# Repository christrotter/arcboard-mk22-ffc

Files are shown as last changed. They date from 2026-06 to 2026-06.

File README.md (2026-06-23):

# arcboard-mk22-ffc
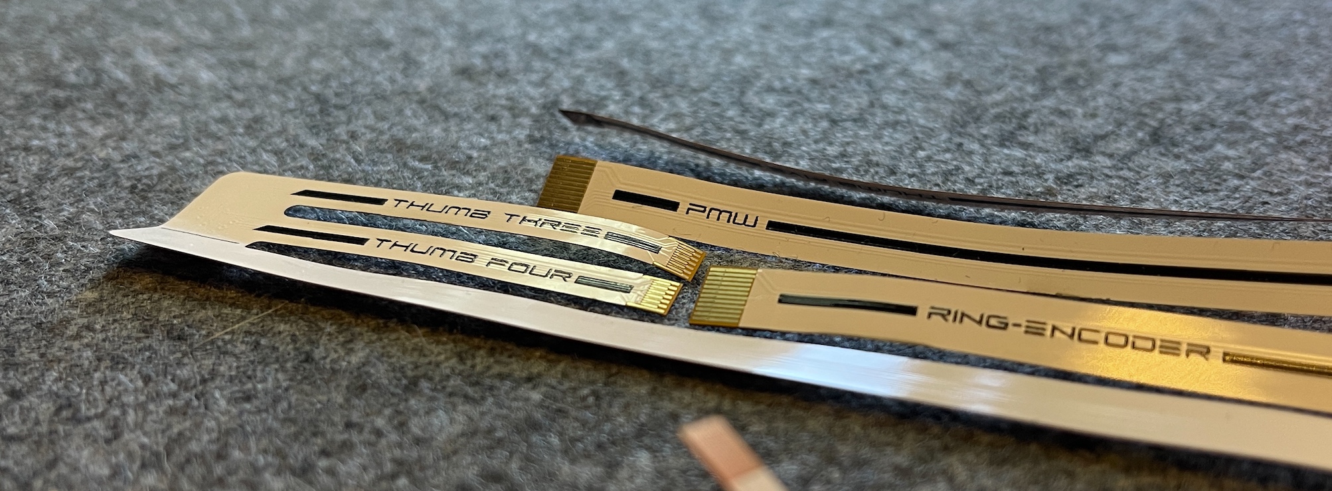
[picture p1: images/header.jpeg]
Header

FFC wiring harness for the Arcboard mk22's [mainboard](https://github.com/christrotter/arcboard-stm32-mk2).  Hooks up a whole pile of keys, peripherals, and indicators with a single cable.  

The goal was to reduce manual soldering as much as possible while also reducing the number of FFC's coming off the mainboard.  [The old mainboard](https://github.com/christrotter/arcboard-stm32) had 10 FFCs coming off at all angles and it was a nightmare to install.

All questions, and more, answered here: 
[Walking through the process of making a custom FFC.](https://docs.google.com/document/d/1AaeZN3C4SzMbZbiK-B96kASK0Lhcgzr27FD6T2ESAdA/edit?usp=sharing)

And if you're interested in learning more about the board itself:
[The mk22 build journal - in great detail.](https://docs.google.com/document/d/1yYdNSWEpefUsuglO4ZzcITcItB_Wx3liXkT57BLO2Ac/edit?usp=sharing)

# ordering
See the 'making a custom FFC' doc for great detail on this.

The different pitch sizes require different total FFC thicknesses.
- 0.3mm-pitch -> 0.2mm thick FFC, including stiffener
- 0.5mm-pitch -> 0.3mm thick FFC, including stiffener (connector specs range from `0.27-0.33mm` to `0.29-0.31mm`)

## peripherals
But what peripherals does this hook up?
- six [Cyboard column PCBs](https://cyboard.digital/products/dactyl-flex-pcbs)
- five [Cyboard thumb key PCBs](https://cyboard.digital/products/dactyl-flex-pcbs)
- [main LED indicator PCB](https://github.com/christrotter/para-led-ogram)
- [ring gear encoder indicator PCB](https://github.com/christrotter/ring-led-pcb)
- [an ST7789v2 LCD adapter PCB](https://github.com/christrotter/lcd-adapter-pcb)
- [two led-backlit EC10 encoders](https://github.com/christrotter/top-encoder-pcb)
- [one non-lit EC10 encoder](https://github.com/christrotter/mouse-encoder-pcb)
- [STM32 mainboard](https://github.com/christrotter/arcboard-stm32)
- [a dpad (5-way)](https://github.com/christrotter/led-pad)
- [three paddles (3x 5-way)](https://github.com/christrotter/multi-paddle-pcb)
- [PMW3360 to FFC](https://github.com/christrotter/charybdis-pmw-3360-sensor-pcb/tree/arcboarding) (*forked from* [Charybdis](https://github.com/Bastardkb/charybdis-pmw-3360-sensor-pcb))

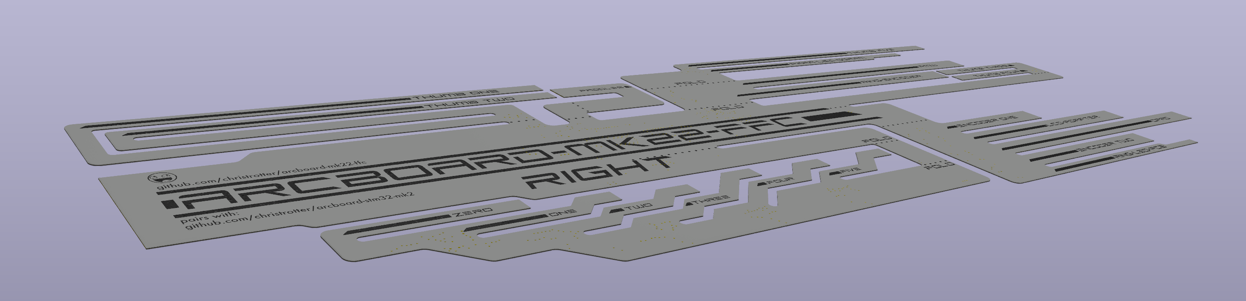
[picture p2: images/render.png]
Render

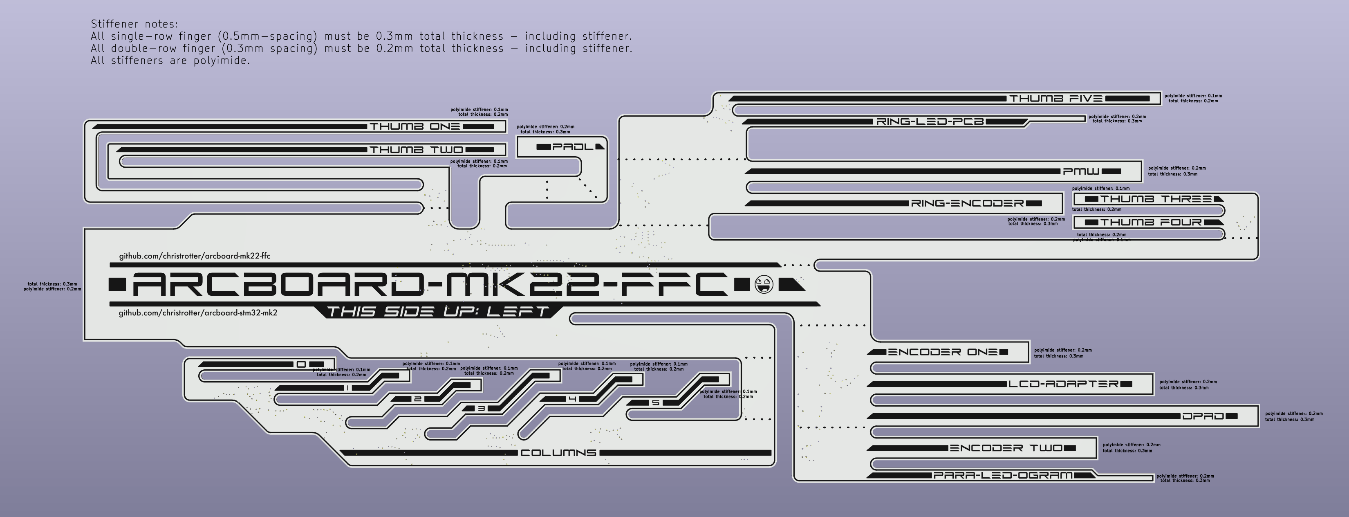
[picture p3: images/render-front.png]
Front

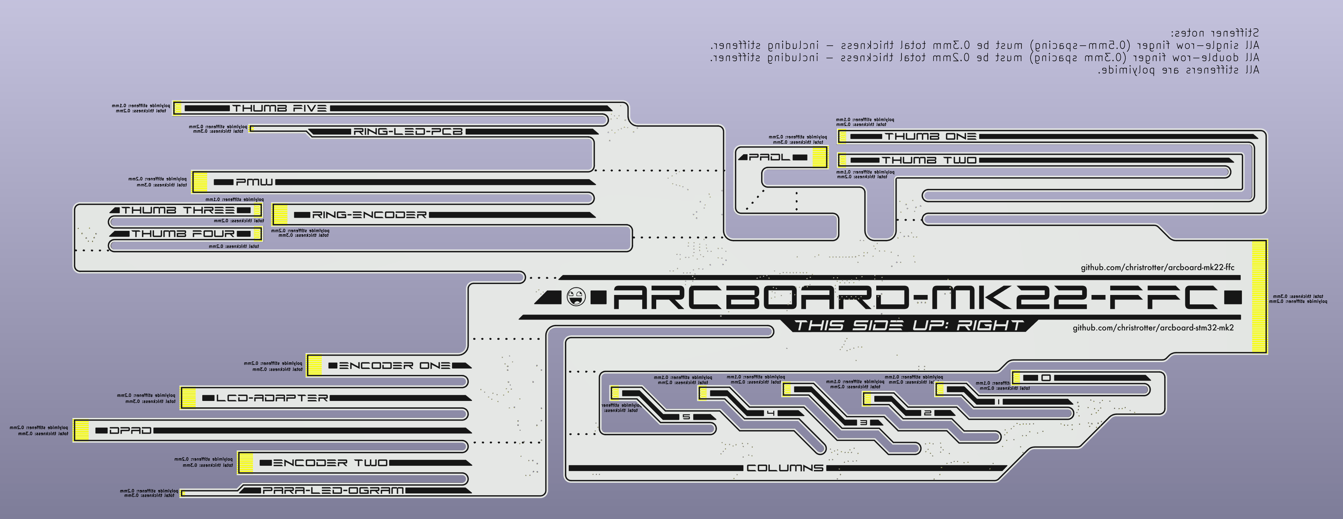
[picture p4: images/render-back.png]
Back


### what if only one half has a trackball?
The theory is I tape or cap off the PMW endpoint on the left half.

## schematic
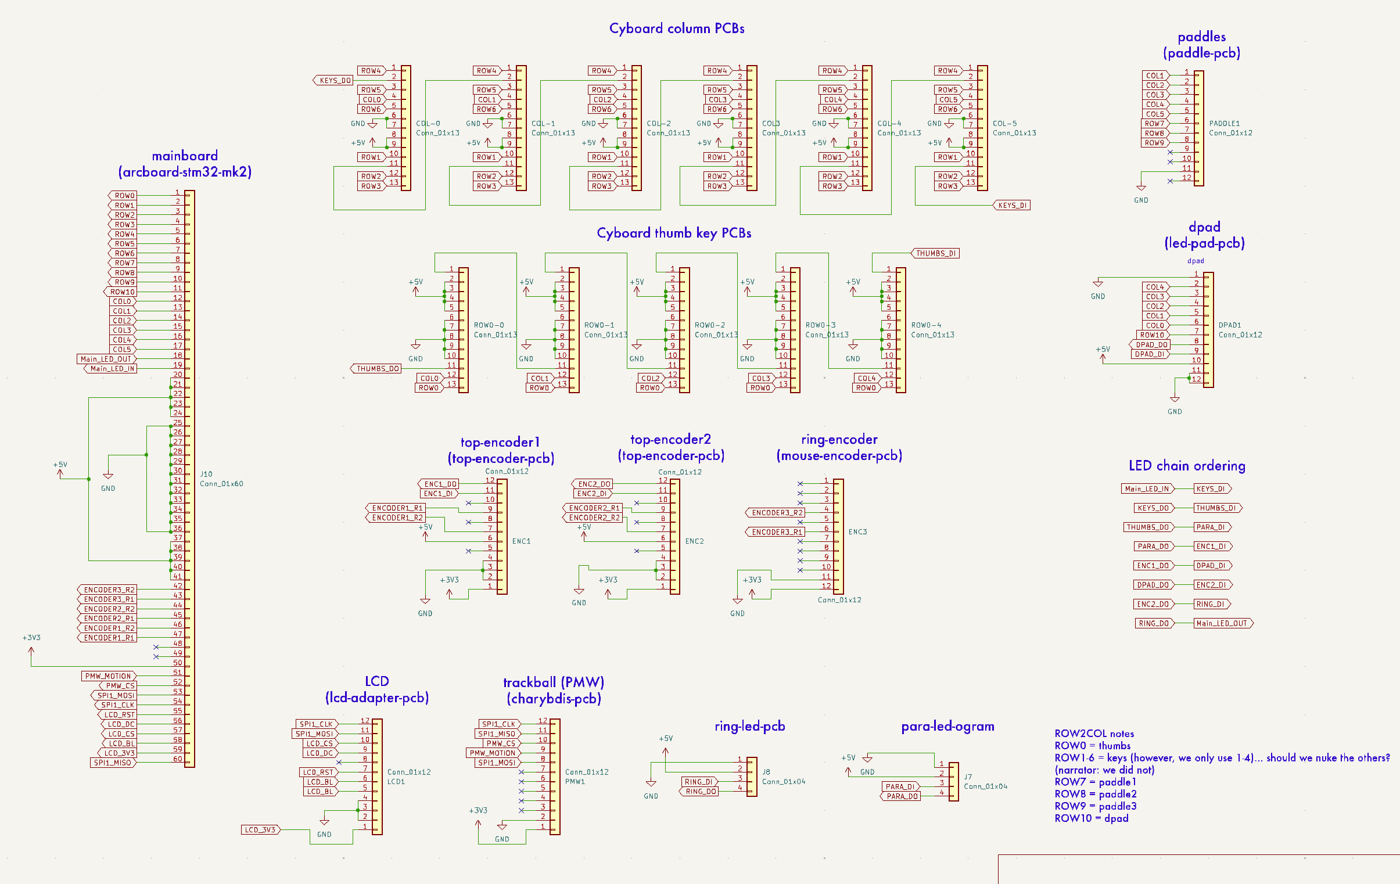
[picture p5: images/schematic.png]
Schematic


## PCB layout
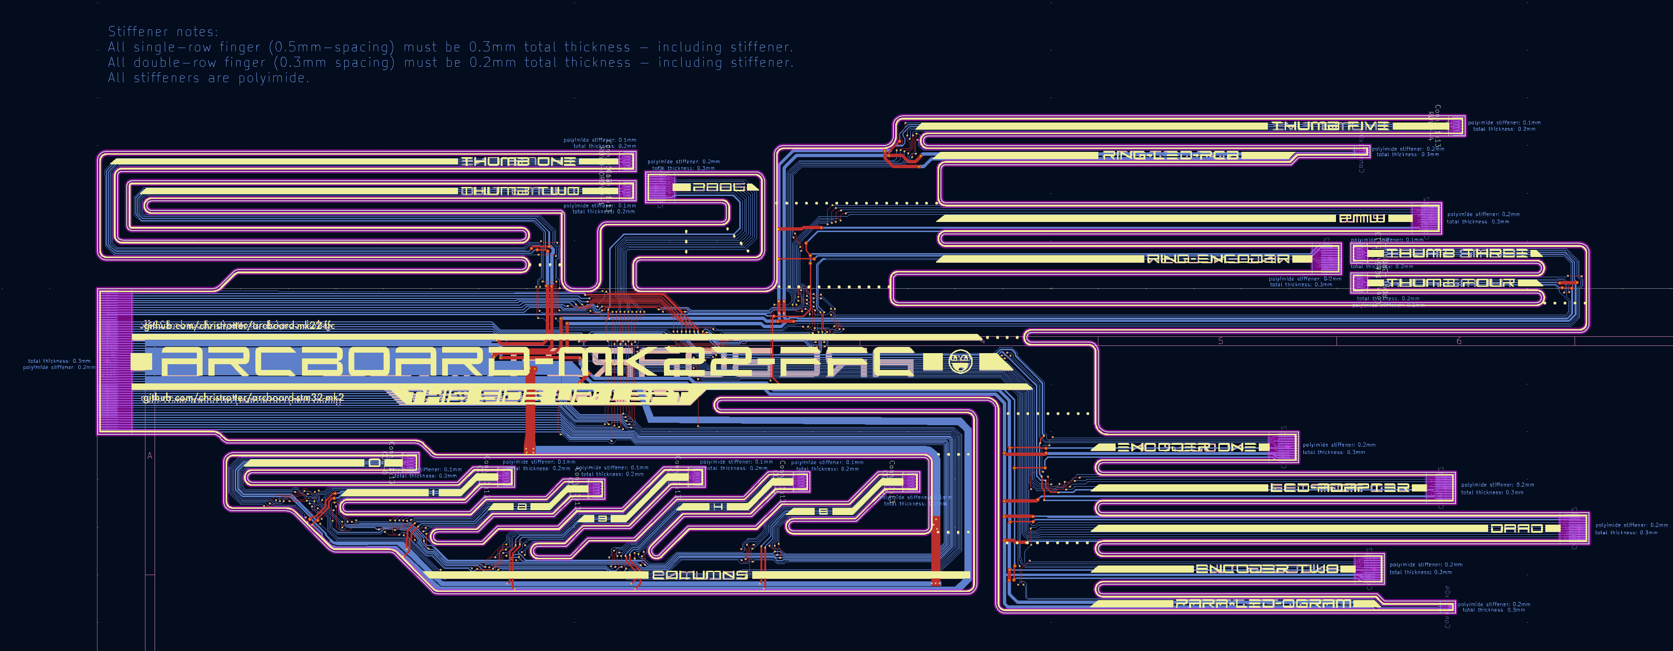
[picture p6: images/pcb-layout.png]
PCB layout


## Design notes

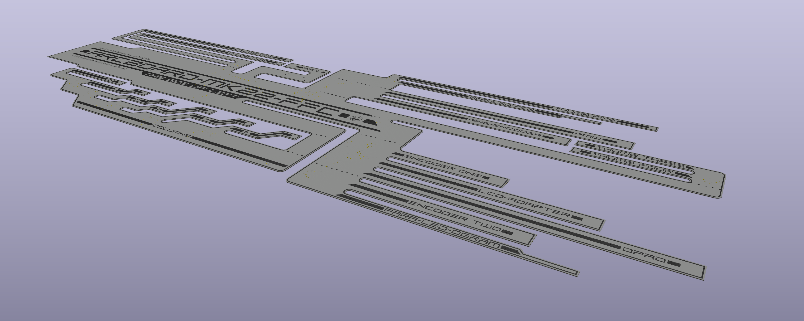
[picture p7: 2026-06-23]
images/render-34.png

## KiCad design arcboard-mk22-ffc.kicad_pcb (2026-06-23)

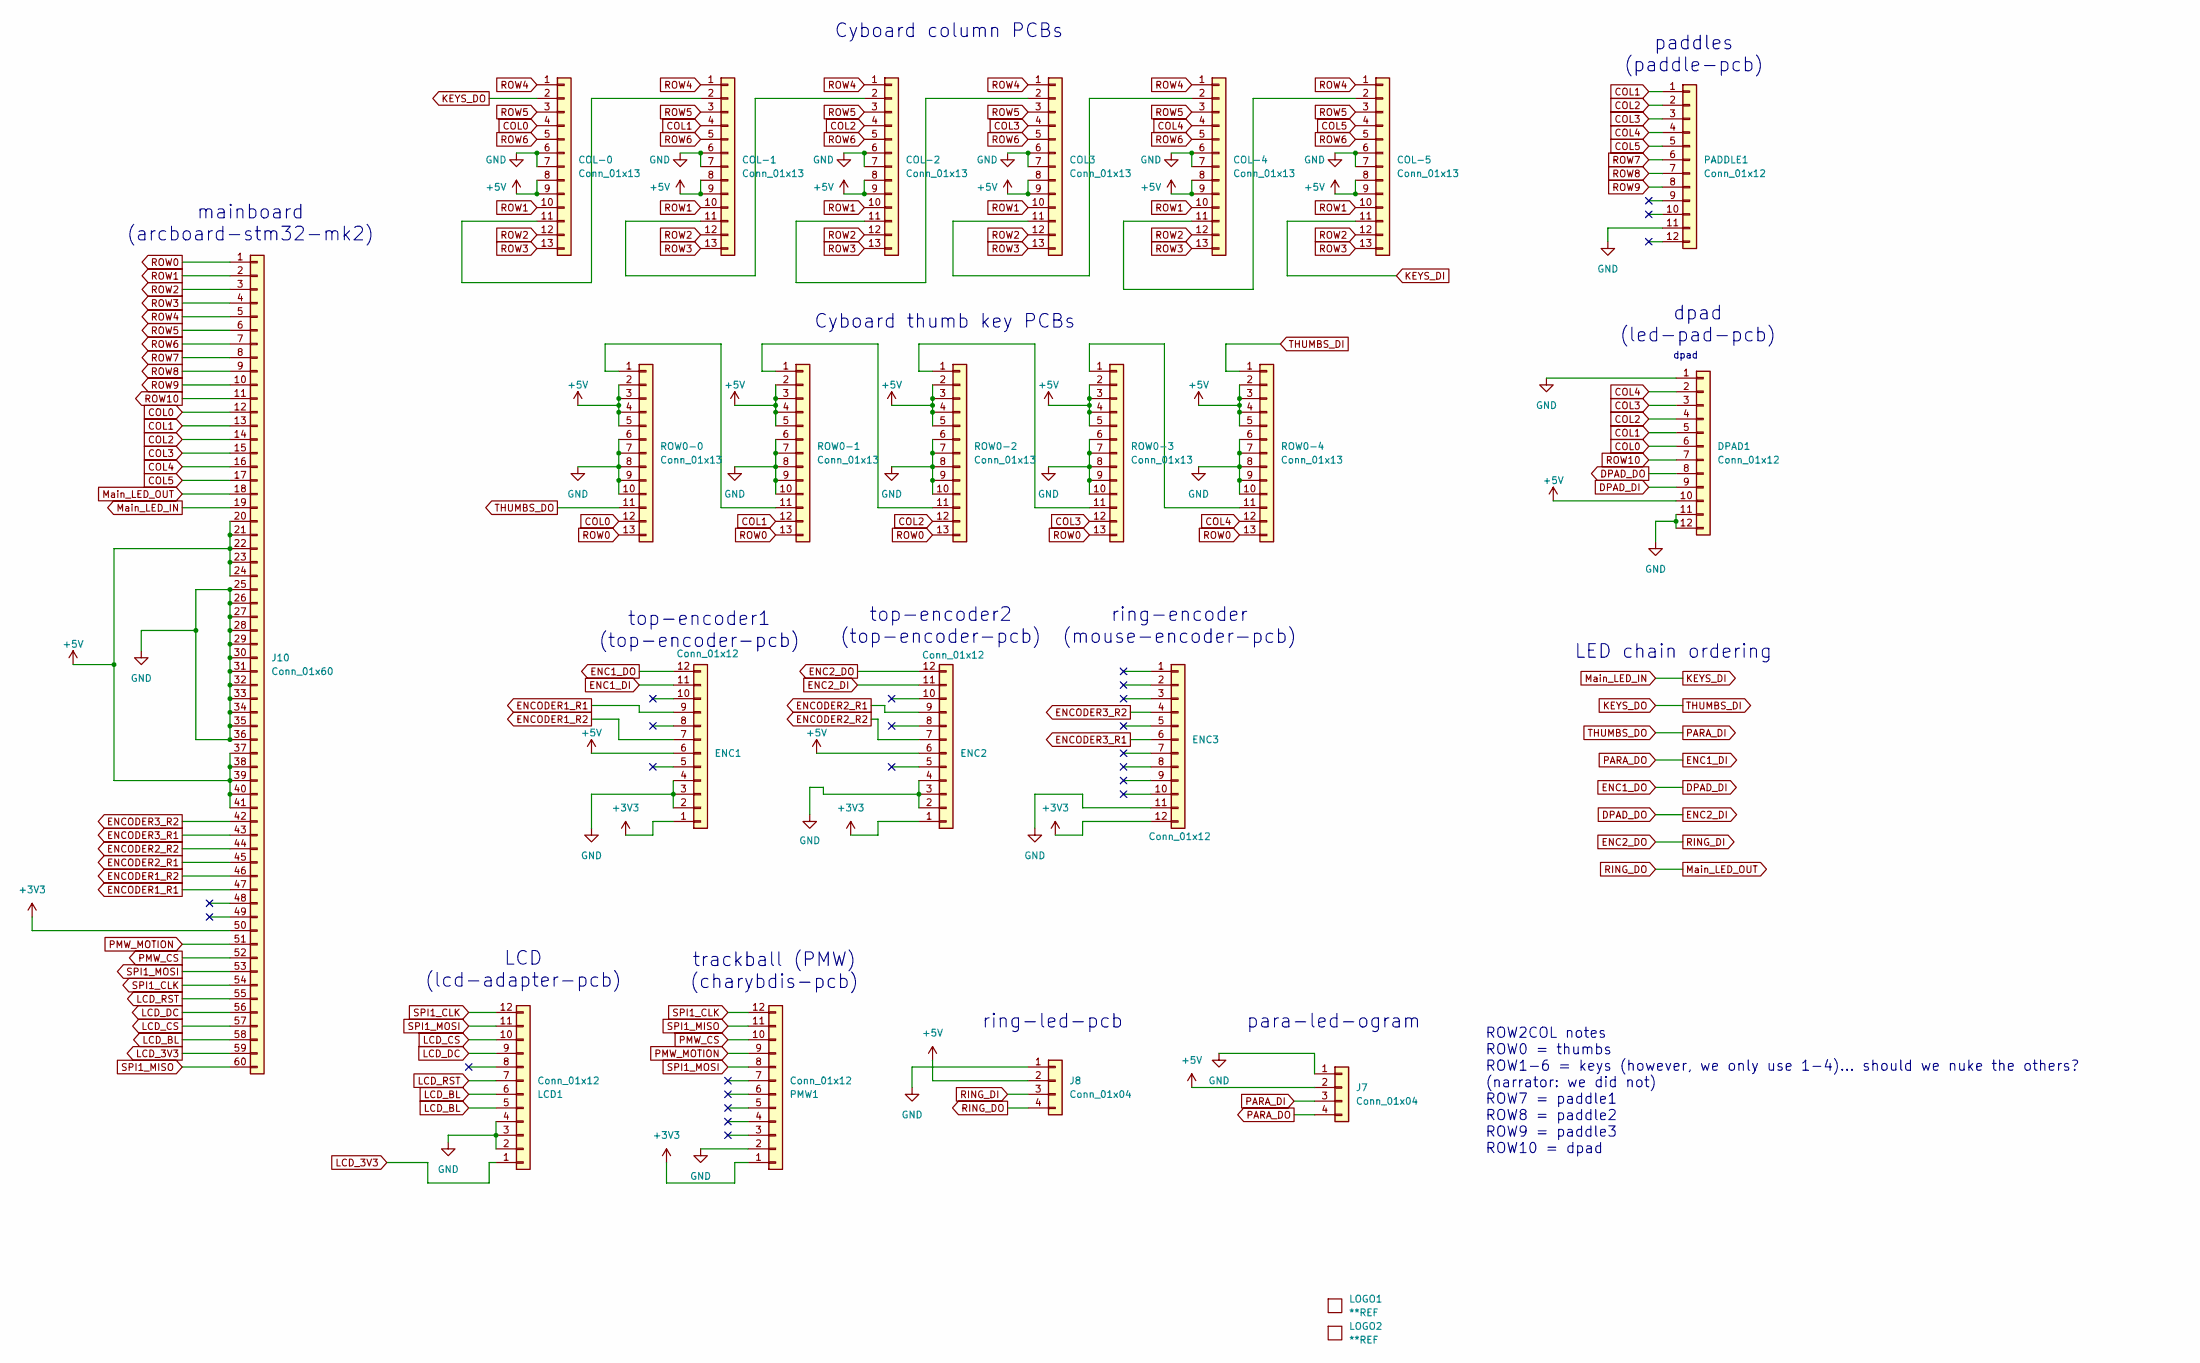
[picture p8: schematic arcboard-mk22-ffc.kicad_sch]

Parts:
COL3: Conn_01x13; FFC Termination 13x0.3 ECT818001568
COL-0, COL-1, COL-2, COL-4, COL-5: Conn_01x13; FFC Termination 13x0.3 ECT818001568
DPAD1: Conn_01x12; ffc-terminator-12pin_0.5mm
ENC1, ENC2, ENC3: Conn_01x12; ffc-terminator-12pin_0.5mm
J7, J8: Conn_01x04; ffc-terminator-4pin_0.5mm
J10: Conn_01x60; FFC-termination-60p-0.5mm
LCD1: Conn_01x12; ffc-terminator-12pin_0.5mm
LOGO1, LOGO2: **REF; awesome-logo
PADDLE1: Conn_01x12; ffc-terminator-12pin_0.5mm
PMW1: Conn_01x12; ffc-terminator-12pin_0.5mm
ROW0-0, ROW0-1, ROW0-2, ROW0-3, ROW0-4: Conn_01x13; FFC Termination 13x0.3 ECT818001568

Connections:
+3V3: ENC1.1, ENC2.1, ENC3.12, J10.50, PMW1.1
+5V: COL3.8, COL3.9, COL-0.8, COL-0.9, COL-1.8, COL-1.9, COL-2.8, COL-2.9, COL-4.8, COL-4.9, COL-5.8, COL-5.9, DPAD1.10, ENC1.6, ENC2.6, J7.2, J8.2, J10.20, J10.21, J10.22, J10.23, J10.24, J10.37, J10.38, J10.39, J10.40, J10.41, ROW0-0.2, ROW0-0.3, ROW0-0.4, ROW0-0.5, ROW0-1.2, ROW0-1.3, ROW0-1.4, ROW0-1.5, ROW0-2.2, ROW0-2.3, ROW0-2.4, ROW0-2.5, ROW0-3.2, ROW0-3.3, ROW0-3.4, ROW0-3.5, ROW0-4.2, ROW0-4.3, ROW0-4.4, ROW0-4.5
COL0: COL-0.4, DPAD1.6, J10.12, ROW0-0.12
COL1: COL-1.4, DPAD1.5, J10.13, PADDLE1.1, ROW0-1.12
COL2: COL-2.4, DPAD1.4, J10.14, PADDLE1.2, ROW0-2.12
COL3: COL3.4, DPAD1.3, J10.15, PADDLE1.3, ROW0-3.12
COL4: COL-4.4, DPAD1.2, J10.16, PADDLE1.4, ROW0-4.12
COL5: COL-5.4, J10.17, PADDLE1.5
DPAD_DI: DPAD1.9, ENC1.12
DPAD_DO: DPAD1.8, ENC2.11
ENC1_DI: ENC1.11, J7.4
ENC2_DO: ENC2.12, J8.3
ENCODER1_R1: ENC1.9, J10.47
ENCODER1_R2: ENC1.7, J10.46
ENCODER2_R1: ENC2.9, J10.45
ENCODER2_R2: ENC2.7, J10.44
ENCODER3_R1: ENC3.6, J10.43
ENCODER3_R2: ENC3.4, J10.42
GND: COL3.6, COL3.7, COL-0.6, COL-0.7, COL-1.6, COL-1.7, COL-2.6, COL-2.7, COL-4.6, COL-4.7, COL-5.6, COL-5.7, DPAD1.1, DPAD1.11, DPAD1.12, ENC1.2, ENC1.3, ENC1.4, ENC2.2, ENC2.3, ENC2.4, ENC3.11, J7.1, J8.1, J10.25, J10.26, J10.27, J10.28, J10.29, J10.30, J10.31, J10.32, J10.33, J10.34, J10.35, J10.36, LCD1.2, LCD1.3, LCD1.4, PADDLE1.11, PMW1.2, ROW0-0.6, ROW0-0.7, ROW0-0.8, ROW0-0.9, ROW0-0.10, ROW0-1.6, ROW0-1.7, ROW0-1.8, ROW0-1.9, ROW0-1.10, ROW0-2.6, ROW0-2.7, ROW0-2.8, ROW0-2.9, ROW0-2.10, ROW0-3.6, ROW0-3.7, ROW0-3.8, ROW0-3.9, ROW0-3.10, ROW0-4.6, ROW0-4.7, ROW0-4.8, ROW0-4.9, ROW0-4.10
KEYS_DI: COL-5.11, J10.19
KEYS_DO: COL-0.2, ROW0-4.1
LCD_3V3: J10.59, LCD1.1
LCD_BL: J10.58, LCD1.5, LCD1.6
LCD_CS: J10.57, LCD1.10
LCD_DC: J10.56, LCD1.9
LCD_RST: J10.55, LCD1.7
Main_LED_OUT: J8.4, J10.18
unnamed: COL-0.11, COL-1.2
unnamed: COL-1.11, COL-2.2
unnamed: COL3.2, COL-2.11
unnamed: COL3.11, COL-4.2
unnamed: COL-4.11, COL-5.2
unnamed: ROW0-0.1, ROW0-1.11
unnamed: ROW0-1.1, ROW0-2.11
unnamed: ROW0-2.1, ROW0-3.11
unnamed: ROW0-3.1, ROW0-4.11
PARA_DI: J7.3, ROW0-0.11
PMW_CS: J10.52, PMW1.10
PMW_MOTION: J10.51, PMW1.9
ROW0: J10.1, ROW0-0.13, ROW0-1.13, ROW0-2.13, ROW0-3.13, ROW0-4.13
ROW1: COL3.10, COL-0.10, COL-1.10, COL-2.10, COL-4.10, COL-5.10, J10.2
ROW2: COL3.12, COL-0.12, COL-1.12, COL-2.12, COL-4.12, COL-5.12, J10.3
ROW3: COL3.13, COL-0.13, COL-1.13, COL-2.13, COL-4.13, COL-5.13, J10.4
ROW4: COL3.1, COL-0.1, COL-1.1, COL-2.1, COL-4.1, COL-5.1, J10.5
ROW5: COL3.3, COL-0.3, COL-1.3, COL-2.3, COL-4.3, COL-5.3, J10.6
ROW6: COL3.5, COL-0.5, COL-1.5, COL-2.5, COL-4.5, COL-5.5, J10.7
ROW7: J10.8, PADDLE1.6
ROW8: J10.9, PADDLE1.7
ROW9: J10.10, PADDLE1.8
ROW10: DPAD1.7, J10.11
SPI1_CLK: J10.54, LCD1.12, PMW1.12
SPI1_MISO: J10.60, PMW1.11
SPI1_MOSI: J10.53, LCD1.11, PMW1.8

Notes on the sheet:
ring-led-pcb
trackball (PMW) (charybdis-pcb)
LCD (lcd-adapter-pcb)
dpad (led-pad-pcb)
mainboard (arcboard-stm32-mk2)
ROW2COL notes ROW0 = thumbs ROW1-6 = keys (however, we only use 1-4)... should we nuke the others? (narrator: we did not) ROW7 = paddle1 ROW8 = paddle2 ROW9 = paddle3 ROW10 = dpad
dpad
LED chain ordering
Cyboard column PCBs
top-encoder2 (top-encoder-pcb)
para-led-ogram
ring-encoder (mouse-encoder-pcb)
Cyboard thumb key PCBs
paddles (paddle-pcb)
top-encoder1 (top-encoder-pcb)

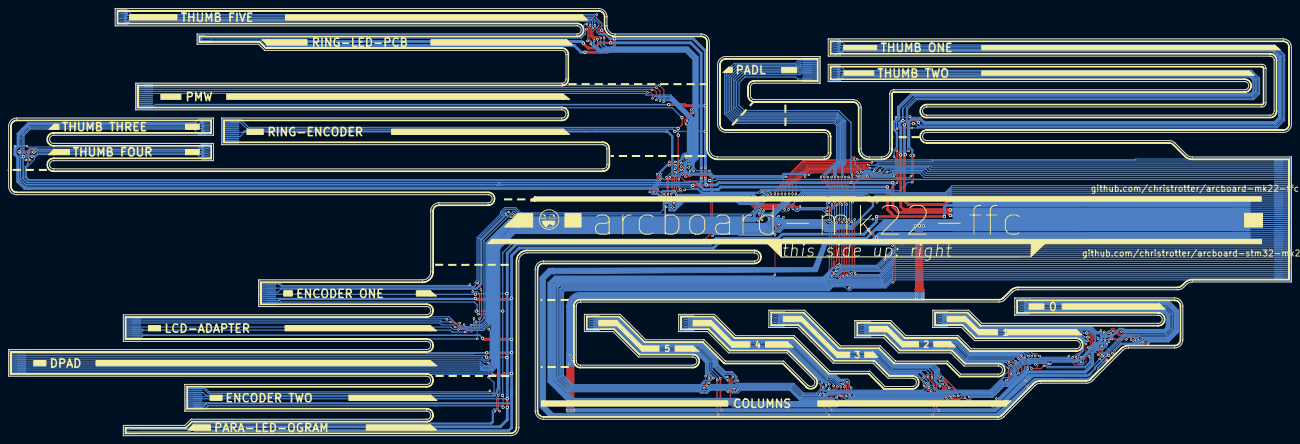
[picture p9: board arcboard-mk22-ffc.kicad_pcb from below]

Board: 2 copper layers, 313.0 x 104.2 mm, 23 parts (11 on the bottom side), 53 nets.

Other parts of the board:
LOGO1#2: **REF; awesome-logo

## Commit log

2026-05-30 finished tracing
    [arcboard-mk22-ffc.kicad_pcb, arcboard-mk22-ffc.kicad_sch]
2026-05-30 fixing folding issues, fattening up the led boards
    [arcboard-mk22-ffc.kicad_pcb, arcboard-mk22-ffc.kicad_sch]
2026-05-30 fixing more cray, starting silkscreen
    [arcboard-mk22-ffc.kicad_pcb]
2026-05-30 first draft silkscreen
    [arcboard-mk22-ffc.kicad_pcb, arcboard-mk22-ffc.kicad_sch]
2026-06-06 silkscreen changes, cleanup prior to easy-eda
    [arcboard-mk22-ffc.kicad_pcb]
2026-06-06 silkscreen changes, fixing drc issues
    [arcboard-mk22-ffc.kicad_pcb]
2026-06-06 first draft readme
    [arcboard-mk22-ffc.kicad_pcb, arcboard-mk22-ffc.kicad_sch]
2026-06-07 adding correct stiffener length reminders
    [arcboard-mk22-ffc.kicad_pcb]
2026-06-19 fixing 0.3 footprint, the di-do mixup, and starting user comments updates
    [arcboard-mk22-ffc.kicad_pcb, arcboard-mk22-ffc.kicad_sch]
2026-06-19 created stiffener layers, updated footprints and comments
    [arcboard-mk22-ffc.kicad_pcb]
2026-06-19 fixing the reversed pinouts for pmw and lcd-adapter
    [arcboard-mk22-ffc.kicad_pcb, arcboard-mk22-ffc.kicad_sch]
2026-06-20 updating ring-led-pcb pinouts
    [arcboard-mk22-ffc.kicad_pcb, arcboard-mk22-ffc.kicad_sch]
2026-06-20 fixing silkscreen
    [arcboard-mk22-ffc.kicad_pcb]
2026-06-20 ordered this
    [arcboard-mk22-ffc.kicad_pcb]
